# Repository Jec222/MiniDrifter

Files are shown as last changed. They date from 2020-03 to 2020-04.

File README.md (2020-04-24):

# Mini Drifter

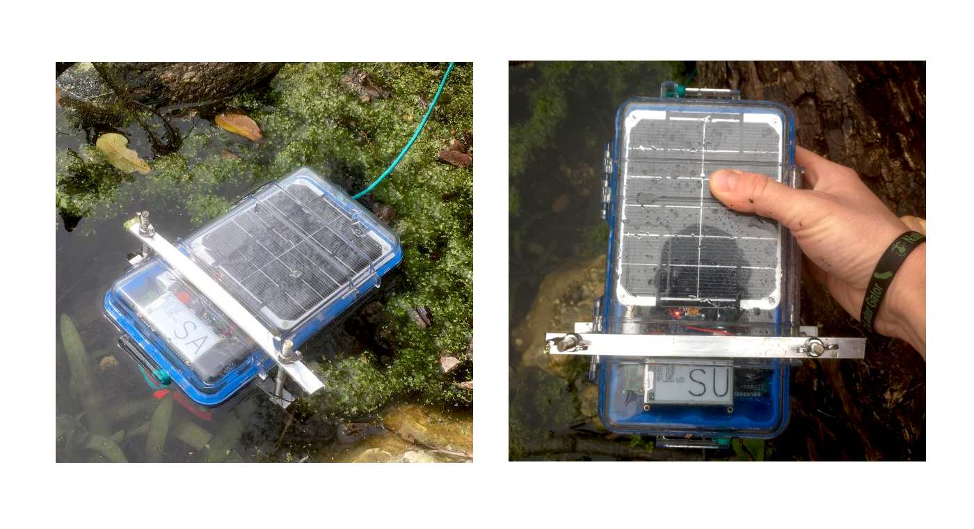
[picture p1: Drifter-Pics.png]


Code and 3d print files for our Senior Design project. The mini drifter is a solar powered smart buoy designed to survive a year with minimal maintenence. It's housing is a modified pelican 1060 case, with a 3d-printed sensor guard epoxied to the bottom.

## Code conventions
### Function prefixes
Code is organized into functions by component, with prefixes denoting the component that the function relates to.
For example:

```
void sd_foo() {
   //Do something with sd card
}
```

this would be the name of a function foo that exists for interacting with the sd card. As a more concrete example, here's our function that sets up the epaper display:
```
void epaper_setup() {
  epd.begin();
  epd.setTextWrap(true);
  epd.setTextSize(2);
}
```

and all other functions related to the epaper display will also begin with "epaper\_"

### Camel case after prefix
After the prefix of the function, camel case is used. For example:
```
void epaper_doTheThing() {
  //Stuff
}
```

## Organization of functions

The first function in the file should be arduino's setup() function, followed by loop(), then the componenent specific functions (which should be grouped together by component).

# 3d print files

The 3d print for the sensor guard is in the SensorGuardPrint folder. It is provided both as a .gcode file and a .stl file to acommadate different types of printers.

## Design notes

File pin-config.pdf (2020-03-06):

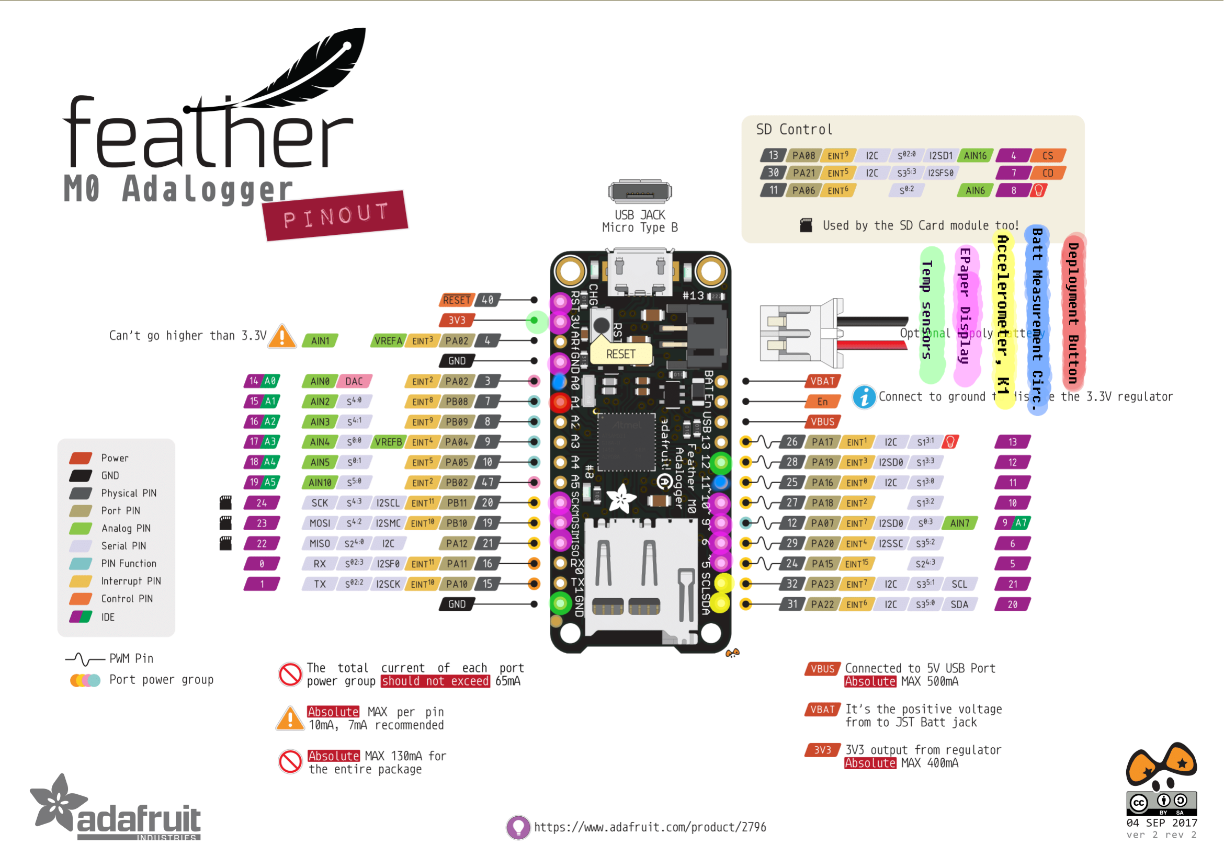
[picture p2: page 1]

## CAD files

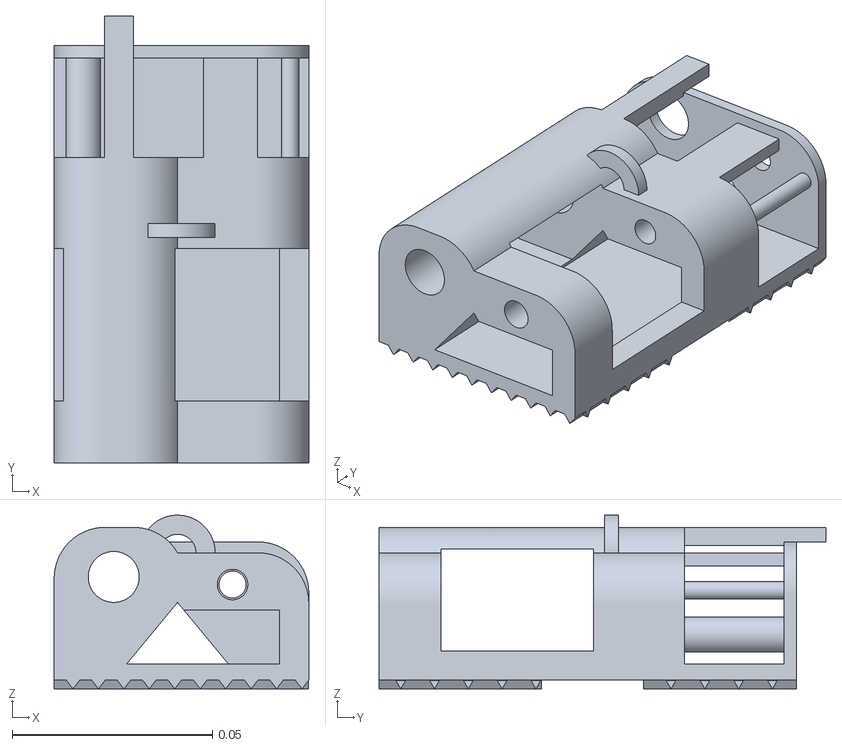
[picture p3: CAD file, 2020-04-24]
SensorGuardPrint/SensorGuard.stl
0.0635 x 0.112 x 0.0433

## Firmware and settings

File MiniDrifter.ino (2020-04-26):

#include <SPI.h>
#include <SD.h>
#include "Adafruit_EPD.h"
#include <OneWire.h>
#include <Adafruit_LIS3DH.h>
#include <Adafruit_Sensor.h>
#include <Wire.h> //For i2c with k1.0
#include <DallasTemperature.h>
#include <RTCZero.h>
#include "icons.h"

#define PIN_LED_RED 13 // Red LED on Pin #13
#define PIN_LED_GREEN 8 // Green LED on Pin #8
#define PIN_LED_STATUS 8
#define PIN_VOLTAGE_BATT 14    // Main Battery Voltage on Pin A0 (14 ide)
#define PIN_VOLTAGE_BATT_CIRC_ENABLE 11 //Enable pin for batt reading circuit
#define SAMPLE_INTERVAL_SECONDS 0 // RTC - Sample interval in seconds
#define SAMPLE_INTERVAL_MINUTES 30

#define PIN_VOLTAGE_BATT_BACKUP A7    // Battery Voltage on Pin A7

enum DaysOfWeek {
  SUNDAY,
  MONDAY,
  TUESDAY,
  WEDNESDAY,
  THURSDAY,
  FRIDAY,
  SATURDAY
};

// Time info for RTC
const byte HOURS = 12;
const byte MINUTES = 45;
const byte SECONDS = 0;

// Date info for RTC
const byte DAY = 13;
const byte MONTH = 3;
const byte YEAR = 20;

typedef struct Timestamp {
  byte hours;
  byte minutes;
  byte seconds;
  byte day;
  byte month;
  byte year;
} Timestamp;

RTCZero rtc;
int nextAlarmTimeMinutes;
int nextAlarmTimeSeconds;
char currentDateAndTime[] = "mm/dd/yy-HH:MM";

#define ONE_WIRE_BUS 12 // Data wire is plugged into port 2 on the Arduino
#define cardSelect 4    //Pin for SD card

//Sets pins for ePaper display
#define EPD_RESET   -1 // can set to -1 and share with microcontroller Reset!
#define EPD_BUSY    -1 // can set to -1 to not use a pin (will wait a fixed delay)
#define SD_CS       5
#define SRAM_CS     6
#define EPD_CS      9
#define EPD_DC      10

//Files on SD card
File logFile;
File errorFile;

const int LOG_DECIMAL_PRECISION = 8;
const int NUM_SAMPLES = 5;
const int TIMESTAMP_SIZE = 8 + strlen("-XX::XX");
const int LOG_DATA_STRING_SIZE = (LOG_DECIMAL_PRECISION * 5) + TIMESTAMP_SIZE + NUM_SAMPLES + 8;
char logLine[LOG_DATA_STRING_SIZE] = "";
char errorLine[750] = ""; // so 1024 is definitely just for now but man, I feel like for our scope, the whole calculation for log_data_string_size is overkill
                          //it does lend well to extension so i guess its alright
const int TEMP_COMP_LENGTH = 8;
char tempComp[TEMP_COMP_LENGTH] = "";


#define ERROR_MESSAGE_DRIFTER_INVERTED "Drifter was inverted, samples weren't taken."
#define ERROR_MESSAGE_NO_SD "No sd card was detected, couldn't log measurements."

struct SystemErrors {
  bool noSdDetected;
  bool drifterInverted;
  bool mainBatteryDepleted;
};

struct SystemErrors systemErrors = {false, false, false};

#define MAX_BATTERY_VOLTAGE 4.2
#define MIN_BATTERY_VOLTAGE 3.0
int mainBatteryLevelPercent;

#define LOW_TEMP_BOUND  30
#define HIGH_TEMP_BOUND 200

const char logFileName[15] = "/DATA.CSV";
const char errorFileName[15] = "/ERRORS.TXT";

#define READ_COMMAND "R"
#define SLEEP_COMMAND "sleep"
#define TEMP_COMPENSATION "T"

//K1.0 stuff
#define K1_ADDRESS 100              //default I2C ID number for EZO EC Circuit.
byte k1ReturnCode;
char k1Data[32];
int k1DelayTime = 570;
char k1InChar;
char *ec;                        //char pointer used in string parsing.
char *tds;                       //char pointer used in string parsing.
char *sal;                       //char pointer used in string parsing.
char *sg;                        //char pointer used in string parsing.
float ec_float;
float tds_float;
float sal_float;
float sg_float;

//For serial input (Serial doesn't work with sleep/wake mode enabled)
bool serialInputComplete;
String serialInput;

//Error Handling Codes
int internal_error_code;
int external_error_code;
int ec_OoB;
int tds_OoB;
int sal_OoB;
bool internal_extra_error;
bool external_extra_error;
bool k1_extra_error;


#define NO_ERROR 0
#define NO_CONNECTION 1
#define FAILED_ONCE   2
#define OUT_OF_BOUNDS 3
#define WITHIN_BOUNDS 4

uint8_t i;
uint8_t samples_taken;

//Accelerometer
Adafruit_LIS3DH accelerometer = Adafruit_LIS3DH();
#define I2C_ADDRESS_ACCELEROMETER 0x18 // change this to 0x19 for alternative i2c address
#define ACCELEROMETER_RANGE LIS3DH_RANGE_4_G  // 2, 4, 8 or 16 G!
typedef struct AccelerometerReading {
  float x;
  float y;
  float z;
};

float intTempF;
float extTempF;

// Setup a oneWire instance to communicate with any OneWire devices (not just Maxim/Dallas temperature ICs)
OneWire oneWire(ONE_WIRE_BUS);

// Pass our oneWire reference to Dallas Temperature.
DallasTemperature sensors(&oneWire);

// arrays to hold device address
DeviceAddress internalThermometer = {0x28, 0x31, 0x74, 0xE3, 0x08, 0x00, 0x00, 0x52};
DeviceAddress externalThermometer = {0x28, 0x9C, 0x32, 0x42, 0x0B, 0x00, 0x00, 0xF3};

//Epaper display
Adafruit_SSD1675 epd(250, 122, EPD_DC, EPD_RESET, EPD_CS, SRAM_CS, EPD_BUSY);

void setup() {
  // put your setup code here, to run once:
  Serial.begin(9600);
  delay(10000);
  Serial.println("\nMini Drifter version 1.0");

  pinMode(PIN_LED_RED, OUTPUT);
  pinMode(PIN_LED_GREEN, OUTPUT);
  pinMode(PIN_LED_STATUS, OUTPUT);
  pinMode(PIN_VOLTAGE_BATT_CIRC_ENABLE, OUTPUT);
  
  digitalWrite(PIN_VOLTAGE_BATT_CIRC_ENABLE, LOW);

  Timestamp initialTime;
  initialTime.hours = HOURS;
  initialTime.minutes = MINUTES;
  initialTime.seconds = SECONDS;
  initialTime.day = DAY;
  initialTime.month = MONTH;
  initialTime.year = YEAR;

  rtc_setup(initialTime);
  sd_setup();
  temp_setup();
  accelerometer_setup();
  k1_setup();
  epaper_setup();

  internal_error_code = 0;
  external_error_code = 0;
  internal_extra_error = false;
  external_extra_error = false;
  k1_extra_error = false;
  ec_OoB = 0;
  tds_OoB = 0;
  sal_OoB = 0;

  i = 0;
  samples_taken = 1;
  k1_sleep();
}

void loop() {
  // put your main code here, to run repeatedly:
  blink(PIN_LED_GREEN, 2);
  blink(PIN_LED_STATUS, 4);
  sd_setup();
  sd_openFiles();
  
  getDate();

  float battN = (drifter_readMainBatteryVoltage() - MIN_BATTERY_VOLTAGE) / (MAX_BATTERY_VOLTAGE - MIN_BATTERY_VOLTAGE);
  if (battN < 0) {
    battN = 0;
  }
  Serial.println(battN);
  mainBatteryLevelPercent = (battN) * 100.0;
  bool needToUpdateEpaper = false;

  if (systemErrors.mainBatteryDepleted) {
    if (mainBatteryLevelPercent > 0) {
      errorFile.write(currentDateAndTime);
      errorFile.write(" succesfully regained power.\n");
      errorFile.flush();
      systemErrors.mainBatteryDepleted = false;
      needToUpdateEpaper = true;
    }
  } else {
    if (mainBatteryLevelPercent == 0) {
      systemErrors.mainBatteryDepleted = true;
      errorFile.write(currentDateAndTime);
      errorFile.write(" Entered power recovery mode.\n");
      errorFile.flush();
      epaper_clear();
      epaper_drawPowerRecoveryModeIcon();
    }
      needToUpdateEpaper = true;
  }

  AccelerometerReading accel = accelerometer_read();
  systemErrors.drifterInverted = accel.z < 0;

  if (!systemErrors.mainBatteryDepleted) {
    if (systemErrors.drifterInverted) {
      /* Drifter is not upright, don't take samples */
    } else {
      if (!systemErrors.noSdDetected) {
        temp_handle_measurement();
        k1_handle_measurement();  
        epaper_clear();
        epaper_drawSensorData();
        if (internal_error_code != 0 || external_error_code != 0 || k1ReturnCode != 1 || ec_OoB != 0 || tds_OoB != 0 || sal_OoB != 0) {
          epaper_drawSensorIcons();
        } else {
          epaper_drawDayCode();
        }
        sd_logError();
        sd_logData();
        needToUpdateEpaper = true;
      }
    }

    drifter_handleSystemErrors();
  }
  Serial.println(needToUpdateEpaper);
  if (needToUpdateEpaper) epaper_update();
  i++;
  samples_taken++;
  sd_closeFiles();
  rtc_enterDeepSleep();
}

void rtc_setup(Timestamp initialTime) {
  rtc.begin();
  rtc.setTime(initialTime.hours, initialTime.minutes, initialTime.seconds);
  rtc.setDate(initialTime.day, initialTime.month, initialTime.year);
  nextAlarmTimeMinutes = initialTime.minutes;
  nextAlarmTimeSeconds = initialTime.seconds;
}

void rtc_enterDeepSleep() {
  nextAlarmTimeSeconds = nextAlarmTimeSeconds + SAMPLE_INTERVAL_SECONDS;
  if (nextAlarmTimeSeconds >= 60) {
    nextAlarmTimeMinutes += 1;
    nextAlarmTimeSeconds = nextAlarmTimeSeconds % 60;
  }
  nextAlarmTimeMinutes = (nextAlarmTimeMinutes + SAMPLE_INTERVAL_MINUTES) % 60;


  rtc.setAlarmSeconds(nextAlarmTimeSeconds);
  rtc.setAlarmMinutes(nextAlarmTimeMinutes);
  rtc.enableAlarm(rtc.MATCH_MMSS); // Match minutes and seconds
  rtc.attachInterrupt(alarmMatch); // Attaches function to be called, currently blank
  delay(50); // Brief delay prior to sleeping not really sure its required

  blink(PIN_LED_GREEN, 2);
  rtc.standbyMode();    // Sleep until next alarm match
  // Code re-starts here after sleep!
}

void alarmMatch() {}

// blink led
void blink(uint8_t LED, uint8_t flashes) {
  uint8_t i;
  for (i=0; i<flashes; i++) {
    digitalWrite(LED, HIGH);
    delay(100);
    digitalWrite(LED, LOW);
    delay(200);
  }
}

void sd_setup() {
  bool logFileEmpty = false;

  if (!SD.begin(cardSelect)) {
    Serial.println("Couldn't initialize SD card");
    systemErrors.noSdDetected = true;
  } else {
    systemErrors.noSdDetected = false;
    logFileEmpty = !SD.exists(logFileName);
  }

  sd_openFiles();

  if(!systemErrors.noSdDetected) {

    if (logFileEmpty) {
      //File didn't previously exist, print header at top
      sprintf(logLine, "mm/dd/yy-HH:MM,Int,Ext,Tds,Sal,Con,Bat%\n");
      logFile.write(logLine);
    }

  logFile.flush();
  }

  sd_closeFiles();
}

void sd_openFiles() {

  if (!systemErrors.noSdDetected) {

    logFile = SD.open(logFileName, FILE_WRITE);
    errorFile = SD.open(errorFileName, FILE_WRITE);

    if (!logFile) {
      Serial.println("Couldn't open log file");
      systemErrors.noSdDetected = true;
    }

    if (!errorFile) {
      Serial.println("Couldn't open error file");
      systemErrors.noSdDetected = true;
    }
  }
}

void sd_closeFiles() {
  if (logFile)
    logFile.close();

  if (errorFile)
    errorFile.close();
}

void sd_logData() {
  sprintf(logLine, "%s,%.2f,%.2f,%.2f,%.2f,%.2f,%.2f\n", currentDateAndTime, intTempF, extTempF, tds_float, sal_float, ec_float, drifter_readMainBatteryVoltage());
  logFile.write(logLine);
  for (int i = 0; i < LOG_DATA_STRING_SIZE; i++) {
    logLine[i] = '\0';
  }
  logFile.flush();
}

void sd_logError() {
  //if there are errors log them otherwise do nothing
  if(internal_error_code != 0 || external_error_code != 0 || k1ReturnCode != 1 || ec_OoB != 0 || tds_OoB != 0 || sal_OoB != 0){

    strcpy(errorLine,currentDateAndTime);
    strcat(errorLine, "\n");

    if(internal_extra_error)
      strcat(errorLine, "\tInternal Temperature sensor connection not established. Trying again ... connection established.\n");

    switch (internal_error_code) {
      case 1:
        strcat(errorLine, "\tInternal Temperature sensor connection not established. Trying again ... could not be established.\n");
        break;

      case 3:
        strcat(errorLine, "\tInternal Temperature out of bounds. Trying again ... sample out of bounds.\n");
        break;

      case 4:
        strcat(errorLine, "\tInternal Temperature out of bounds. Trying again ... sample within bounds.\n");
        break;
      default:
        break;
    }

    if(external_extra_error)
      strcat(errorLine, "\tExternal Temperature sensor connection not established. Trying again ... connection established.\n");

    switch (external_error_code) {
      case 1:
        strcat(errorLine, "\tExternal Temperature sensor connection not established. Trying again ... could not be established.\n");
        break;

      case 3:
        strcat(errorLine, "\tExternal Temperature out of bounds. Trying again ... sample out of bounds.\n");
        break;

      case 4:
        strcat(errorLine, "\tExternal Temperature out of bounds. Trying again ... sample within bounds.\n");
        break;
      default:
        break;
    }

    switch(k1ReturnCode){
      case 0:
        strcat(errorLine, "\tK1 Probe - Data returned Null\n");
        break;

      case 2:
        strcat(errorLine, "\tK1 Probe - Command has failed. Trying again ... command failure.\n");
        break;

      case 254:
        strcat(errorLine, "\tK1 Probe - Command pending error.\n");
        break;

      case 255:
        strcat(errorLine, "\tK1 Probe - Connection not established ... could not be established.\n");
        break;
      default:
        break;
    }

    if(k1_extra_error)
      strcat(errorLine, "\tK1 Probe - Connection not established ... connection established.\n");

    switch(tds_OoB){
      case 1:
        strcat(errorLine, "\tTDS sensor out of bounds. Trying again ... sample within bounds\n");
        break;
      case 2:
        strcat(errorLine, "\tTDS sensor out of bounds. Trying again ... sample out of bounds\n");
        break;
      default:
        break;
    }
    switch(ec_OoB){
      case 1:
        strcat(errorLine, "\tConductivity sensor out of bounds. Trying again ... sample within bounds\n");
        break;
      case 2:
        strcat(errorLine, "\tConductivity sensor out of bounds. Trying again ... sample out of bounds\n");
        break;
      default:
        break;
    }
    switch(sal_OoB){
      case 1:
        strcat(errorLine, "\tSalinity sensor out of bounds. Trying again ... sample within bounds\n");
        break;
      case 2:
        strcat(errorLine, "\tSalinity sensor out of bounds. Trying again ... sample out of bounds\n");
        break;
      default:
        break;
    }


    internal_error_code = 0;
    external_error_code = 0;
    ec_OoB = 0;
    tds_OoB = 0;
    sal_OoB = 0;
    internal_extra_error = false;
    external_extra_error = false;
    k1_extra_error = false;

    errorFile.write(errorLine);
    for (int i = 0; i < 128; i++) {
      errorLine[i] = '\0';
    }
  }
}

void getDate(){
  sprintf(currentDateAndTime, "%d/%d/%d-%d:%02d", rtc.getMonth(), rtc.getDay(), rtc.getYear(), rtc.getHours(), rtc.getMinutes());
}

void drifter_handleSystemErrors() {

  if (systemErrors.noSdDetected) {
    sd_closeFiles();
    epd.clearBuffer();
    epaper_drawSdCardErrorIcon();
    sd_setup();
  }

  if (systemErrors.drifterInverted) {
    errorFile.write(currentDateAndTime);
    errorFile.write(" ");
    errorFile.write(ERROR_MESSAGE_DRIFTER_INVERTED);
    errorFile.write("\n");
    errorFile.flush();
  }
}

void epaper_setup() {
  epd.begin();
  epd.setTextWrap(true);
  epd.setTextSize(1);
  epd.setTextColor(EPD_BLACK);
}

void epaper_draw1BitIcon(const unsigned char *bytes, const int width, const int height, const int xPos, const int yPos) {
  for (int y = 0; y < height; y++) {
    for (int x = 0; x < width; x++) {
      if (icon_pixelIsOn(bytes, width, height, x, y)) {
        epd.drawPixel(xPos + x, yPos + y, EPD_BLACK);
      }
    }
  }
}

void epaper_drawPowerRecoveryModeIcon() {
  epd.setTextSize(1);
  epd.setCursor(0, 25);
  epd.print("Entered power\nrecovery mode\n");
  epd.print(currentDateAndTime);
  epaper_draw1BitIcon(BATTERY_ICON_BYTES, BATTERY_ICON_WIDTH, BATTERY_ICON_HEIGHT, 121, 13);
}

void epaper_drawSdCardErrorIcon() {
  epd.setTextSize(1);
  epd.setCursor(0, 25);
  epd.print("No SD card...\n\nPlease insert\nSD.");
  epaper_draw1BitIcon(NO_SD_ICON_BYTES, NO_SD_ICON_WIDTH, NO_SD_ICON_HEIGHT, 121, 13);
}

void epaper_clear() {
  epd.clearBuffer();
}

void epaper_update() {
  epd.display();
}

void epaper_drawSensorData() {
    epd.setCursor(2, 2);
    epd.setTextSize(1);
    if (systemErrors.drifterInverted) {
      epd.print("Not upright");
      epd.print("\nInt: ");
      epd.print(intTempF);
      epd.print("\nExt: NA");
      epd.print("\nTDS: NA");
      epd.print("\nCon: NA");
      epd.print("\nSal: NA");
      epd.print("\nBat: ");
      epd.print(mainBatteryLevelPercent);
      epd.print("%, ");
      epd.print(drifter_readMainBatteryVoltage());
      epd.print("V\n");
      epd.print("%\n");
    } else {
      epd.print("MiniDrifter");
      epd.print("\nInt: ");
      epd.print(intTempF);
      epd.print("\nExt: ");
      epd.print(extTempF);
      epd.print("\nTDS: ");
      epd.print(tds_float);
      epd.print("\nCon: ");
      epd.print(ec_float);
      epd.print("\nSal: ");
      epd.print(sal_float);
      epd.print("\nBat: ");
      epd.print(mainBatteryLevelPercent);
      epd.print("%, ");
      epd.print(drifter_readMainBatteryVoltage());
      epd.print("V\n");
      epd.print(samples_taken);
      epd.print(" samples taken");
    }
}

void epaper_drawSensorIcons() {
    epaper_draw1BitIcon(SENSOR_ICON_BYTES, SENSOR_ICON_WIDTH, SENSOR_ICON_HEIGHT, 121, 0);
    
    int x_dimension = 70;
    int y_dimension = 95;
    int offset = 10;

    epd.setCursor(x_dimension, y_dimension);
  
    switch(internal_error_code){
      case NO_ERROR:
        break;
      case NO_CONNECTION:
        epd.print("Int temp sensor disconnected");
        y_dimension += offset;
        break;
      case OUT_OF_BOUNDS:
        epd.print("Int temp out of bounds");
        y_dimension += offset; 
        break;
      default:
        break;
    }

    epd.setCursor(x_dimension, y_dimension);
    
    switch(external_error_code){
      case NO_ERROR:
        break;
      case NO_CONNECTION:
        epd.print("Ext temp sensor disconnected");
        y_dimension += offset;
        break;
      case OUT_OF_BOUNDS:
        epd.print("Ext temp out of bounds");
        y_dimension += offset;   
        break;
      default:
        break;
    }

    epd.setCursor(x_dimension, y_dimension);
        
    switch(k1ReturnCode){
      case 0:
        epd.print("K1 - Null values");
        break;
      case 2:
        epd.print("K1 - Command Failed");
        break;
      case 254:
        epd.print("K1 - Pending");
        break;
      case 255:
        epd.print("K1 Chip disconnected");
        break;
      case 1:
      case 3:
      case 256:
        if(ec_OoB == 1 || tds_OoB == 1 || sal_OoB == 1){
          epd.print("K1 - out of bounds");
          //write "K1 Probe disconnected"
        }
        break;
      default:
        break;
    }
}

void epaper_drawDayCode() {
  const int dayOfWeek = drifter_getDayOfWeek(rtc.getYear(), rtc.getMonth(), rtc.getDay());

  Serial.print("day of week = ");
  Serial.println(dayOfWeek);
  
  switch(dayOfWeek) {
    case SUNDAY:
      epaper_draw1BitIcon(SUNDAY_ICON_BYTES, SUNDAY_ICON_WIDTH, SUNDAY_ICON_HEIGHT, 105, 9);
    break;
    case MONDAY:
      epaper_draw1BitIcon(MONDAY_ICON_BYTES, MONDAY_ICON_WIDTH, MONDAY_ICON_HEIGHT, 105, 9);
    break;
    case TUESDAY:
      epaper_draw1BitIcon(TUESDAY_ICON_BYTES, TUESDAY_ICON_WIDTH, TUESDAY_ICON_HEIGHT, 105, 9);
    break;
    case WEDNESDAY:
      epaper_draw1BitIcon(WEDNESDAY_ICON_BYTES, WEDNESDAY_ICON_WIDTH, WEDNESDAY_ICON_HEIGHT, 105, 9);
    break;
    case THURSDAY:
      epaper_draw1BitIcon(THURSDAY_ICON_BYTES, THURSDAY_ICON_WIDTH, THURSDAY_ICON_HEIGHT, 105, 9);
    break;
    case FRIDAY:
      epaper_draw1BitIcon(FRIDAY_ICON_BYTES, FRIDAY_ICON_WIDTH, FRIDAY_ICON_HEIGHT, 105, 9);
    break;
    case SATURDAY:
      epaper_draw1BitIcon(SATURDAY_ICON_BYTES, SATURDAY_ICON_WIDTH, SATURDAY_ICON_HEIGHT, 105, 9);
    break;
    default:
    break;
  }
}

void temp_setup() {
  // locate devices on the bus
  sensors.begin();

  //parasite power is off

  // set the resolution to 9 bit (Each Dallas/Maxim device is capable of several different resolutions)
  sensors.setResolution(internalThermometer, 9);
}

void temp_readTemperatures() {
  sensors.requestTemperatures();
  float tempC = sensors.getTempC(internalThermometer);
  intTempF = DallasTemperature::toFahrenheit(tempC);

  tempC = sensors.getTempC(externalThermometer);
  extTempF = DallasTemperature::toFahrenheit(tempC);
}

/*
 *Takes a reading from the temperature sensors
 *Checks for a valid connection by comparing the received data against a default value.
 *
 *thinking about using an error code like the K1 uses.
 *int internal_error_code;
 *int external_error_code;
 *0 = no error. should be by default
 *1 = connection failed twice
 *2 = failed but connection established
 *3 = out of bounds twice
 *4 = out of bounds but inside second try
 *internal_extra error = failed to connect once but worked second time BUT out of bounds. instead of writing 2 extra cases each time I'll write 3 bool values for each sensor.
 *error code reset in the single error write
 */
void temp_handle_measurement(){
  temp_readTemperatures();



  //connection check
  if(intTempF < -196){
    temp_readTemperatures();

    if(intTempF < -196){
      internal_error_code = 1;
      intTempF = -1;
    }
    else
      internal_error_code = 2;
  }
  //Bounds check
  if(internal_error_code == 0 || internal_error_code == 2){
    if(internal_error_code == 2)
      internal_extra_error = true;
    if(intTempF < LOW_TEMP_BOUND || intTempF > HIGH_TEMP_BOUND){
      temp_readTemperatures();
      if(intTempF < LOW_TEMP_BOUND || intTempF > HIGH_TEMP_BOUND){
        intTempF = -1;
        internal_error_code = 3;
      }
      else
        internal_error_code = 4;
    }
  }

  //connection check
  if(extTempF < -196){
    temp_readTemperatures();
    if(extTempF < -196){
      external_error_code = 1;
      extTempF = -1;
    }
    else
      external_error_code = 2;
  }

  //Bounds check
  if(external_error_code == 0 || external_error_code == 2){
    if(external_error_code == 2)
      external_extra_error = true;
    if(extTempF < LOW_TEMP_BOUND || extTempF > HIGH_TEMP_BOUND){
      temp_readTemperatures();
      if(extTempF < LOW_TEMP_BOUND || extTempF > HIGH_TEMP_BOUND){
        extTempF = -1;
        external_error_code = 3;
      }
      else
        external_error_code = 4;
    }
  }
}

void accelerometer_setup() {
  if (!accelerometer.begin(I2C_ADDRESS_ACCELEROMETER)) {
    Serial.println("Couldnt start accelerometer");
  } else {
    accelerometer.setRange(ACCELEROMETER_RANGE);
  }
}
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

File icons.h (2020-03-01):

#ifndef MINI_DRIFTER_ICONS_H
#define MINI_DRIFTER_ICONS_H

// Pass in the bytes of the 1 bit-per-pixel icon along with it's width, height, and the desired x/y
// coordinates to see if the specified pixel is on or off. These icons are essentially bit masks that tell 
// you where to draw pixels and where to leave the screen blank. An external program was written in C to
// convert black and white images to these 1bpp bit masks and output them as a C array, which was then
// copy/pasted into this file.

bool icon_pixelIsOn(const unsigned char *iconBytes, const int iconWidth, const int iconHeight, int x, int y) {
  if (x >= iconWidth || y >= iconHeight || x < 0 || y < 0) {
    return false;
  }
  
  const int widthBytes = iconWidth >> 3;
  const int bitShift = 7 - (x % 8);
  
  return iconBytes[(y*widthBytes) + (x >> 3)] & (1 << bitShift);
}

const int NO_SD_ICON_WIDTH = 128;
const int NO_SD_ICON_HEIGHT = 96;

const unsigned char NO_SD_ICON_BYTES[1536] = {
  0x00, 0x01, 0xff, 0xff, 0xf8, 0x00, 0xff, 0xff, 0xff, 0xff, 0xff, 0xff, 0xff, 0xff, 0xff, 0xfe, 
  0x00, 0x03, 0xff, 0xff, 0xf8, 0x01, 0xff, 0xff, 0xff, 0xff, 0xff, 0xff, 0xff, 0xff, 0xff, 0xfe, 
  0x00, 0x07, 0xff, 0xff, 0xfc, 0x01, 0xff, 0xff, 0xff, 0xff, 0xff, 0xff, 0xff, 0xff, 0xff, 0xfe, 
  0x00, 0x0f, 0xff, 0xff, 0xfc, 0x03, 0xff, 0xff, 0xff, 0xff, 0xff, 0xff, 0xff, 0xff, 0xff, 0xfe, 
  0x00, 0x1f, 0x00, 0x00, 0x0f, 0xff, 0x80, 0x00, 0x00, 0x00, 0x00, 0x00, 0x00, 0x00, 0x00, 0x1e, 
  0x00, 0x3e, 0x00, 0x00, 0x07, 0xff, 0x00, 0x00, 0x00, 0x00, 0x00, 0x00, 0x00, 0x00, 0x00, 0x1e, 
  0x00, 0x7c, 0x00, 0x00, 0x07, 0xff, 0x00, 0x00, 0x00, 0x00, 0x00, 0x00, 0x00, 0x00, 0x00, 0x1e, 
  0x00, 0xf8, 0x00, 0x00, 0x03, 0xfe, 0x00, 0x00, 0x00, 0x00, 0x00, 0x00, 0x00, 0x00, 0x00, 0x1e, 
  0x01, 0xf0, 0x00, 0x00, 0x00, 0x00, 0x00, 0x00, 0x00, 0x00, 0x00, 0x00, 0x00, 0x00, 0x00, 0x1e, 
  0x03, 0xe0, 0x00, 0x00, 0x00, 0x00, 0x00, 0x00, 0x00, 0x00, 0x00, 0x00, 0x00, 0x00, 0x00, 0x1e, 
  0x07, 0xc0, 0x01, 0x80, 0x00, 0x00, 0x00, 0x00, 0x00, 0x00, 0x00, 0x00, 0x00, 0x00, 0x00, 0x1e, 
  0x0f, 0x80, 0x1f, 0x80, 0x00, 0x00, 0x00, 0x00, 0x00, 0x00, 0x00, 0x00, 0x00, 0x00, 0x00, 0x1e, 
  0x1f, 0x00, 0x7f, 0x80, 0x00, 0x00, 0x00, 0x00, 0x00, 0x00, 0x00, 0x00, 0x00, 0x00, 0x00, 0x1e, 
  0x3e, 0x00, 0x7f, 0x80, 0x00, 0x00, 0x00, 0x00, 0x00, 0x00, 0x00, 0x00, 0x00, 0x00, 0x00, 0x1e, 
  0x7c, 0x00, 0x1f, 0x80, 0x00, 0x00, 0x00, 0x00, 0x00, 0x00, 0x00, 0x00, 0x00, 0x00, 0x00, 0x1e, 
  0xf8, 0x00, 0x01, 0x80, 0x00, 0x00, 0x00, 0x00, 0x00, 0x00, 0x00, 0x00, 0x00, 0x00, 0x00, 0x1e, 
  0xf8, 0x00, 0x00, 0x00, 0x00, 0x00, 0x00, 0x00, 0x00, 0x00, 0x00, 0x00, 0x00, 0x00, 0x00, 0x1e, 
  0xf8, 0x00, 0x00, 0x00, 0x00, 0x00, 0x00, 0x00, 0x00, 0x00, 0x00, 0x00, 0x00, 0x00, 0x00, 0x1e, 
  0xf8, 0x00, 0x00, 0x00, 0x00, 0x00, 0x00, 0x00, 0x08, 0x00, 0x00, 0x00, 0x00, 0x00, 0x00, 0x1e, 
  0xf8, 0x00, 0x00, 0x00, 0x00, 0x00, 0x0f, 0xf0, 0x3e, 0x00, 0x00, 0x00, 0x00, 0x00, 0x00, 0x1e, 
  0xf8, 0x00, 0x00, 0x00, 0x00, 0x00, 0x1f, 0xf8, 0x3f, 0x00, 0x00, 0x00, 0x00, 0x00, 0x00, 0x1e, 
  0xf8, 0x00, 0x00, 0x00, 0x00, 0x00, 0x1f, 0xfc, 0x7f, 0x00, 0x00, 0x00, 0x00, 0x00, 0x00, 0x1e, 
  0xf8, 0x00, 0x00, 0x00, 0x00, 0x00, 0x3e, 0x7c, 0x7f, 0x80, 0x00, 0x00, 0x00, 0x00, 0x00, 0x1e, 
  0xf8, 0x00, 0x00, 0x00, 0x00, 0x00, 0x3c, 0x3c, 0xff, 0xc0, 0x00, 0x00, 0x00, 0x00, 0x00, 0x1e, 
  0xf8, 0x00, 0x00, 0x00, 0x00, 0x00, 0x3c, 0x3c, 0xff, 0xc0, 0x00, 0x00, 0x00, 0x00, 0x00, 0x1e, 
  0xf8, 0x00, 0x00, 0x00, 0x00, 0x00, 0x3e, 0x7c, 0xff, 0xc0, 0x00, 0x00, 0x00, 0x00, 0x00, 0x1e, 
  0xf8, 0x00, 0x00, 0x00, 0x00, 0x00, 0x1f, 0xfc, 0xff, 0xc0, 0x00, 0x00, 0x00, 0x00, 0x00, 0x1e, 
  0xf8, 0x00, 0x00, 0x00, 0x00, 0x00, 0x1f, 0xf9, 0xff, 0xc0, 0x00, 0x00, 0x00, 0x00, 0x00, 0x1e, 
  0xf8, 0x00, 0x00, 0x00, 0x00, 0x00, 0x0f, 0xf1, 0xff, 0xe0, 0x00, 0x00, 0x00, 0x00, 0x00, 0x1e, 
  0xf8, 0x00, 0x00, 0x00, 0x00, 0x00, 0x00, 0x01, 0xc7, 0xe0, 0x00, 0x00, 0x00, 0x00, 0x00, 0x1e, 
  0xf8, 0x00, 0x00, 0x00, 0x00, 0x00, 0x0e, 0x01, 0xc7, 0xe0, 0x00, 0x00, 0x00, 0x00, 0x00, 0x1e, 
  0xf8, 0x00, 0x00, 0x00, 0x00, 0x00, 0x1e, 0x01, 0xc3, 0xe0, 0x00, 0x00, 0x00, 0x00, 0x00, 0x1e, 
  0xf8, 0x00, 0x00, 0x00, 0x00, 0x00, 0x3e, 0x01, 0xc3, 0xe0, 0x00, 0x00, 0x00, 0x00, 0x00, 0x1e, 
  0xf8, 0x00, 0x00, 0x00, 0x00, 0x00, 0x3e, 0x01, 0xc3, 0xe0, 0x00, 0x00, 0x00, 0x00, 0x00, 0x1e, 
  0xf8, 0x00, 0x00, 0x00, 0x00, 0x00, 0x3c, 0x00, 0x03, 0xe0, 0x00, 0x00, 0x00, 0x00, 0x00, 0x1e, 
  0xf8, 0x00, 0x00, 0x00, 0x00, 0x00, 0x3c, 0x01, 0xc3, 0xe0, 0x00, 0x00, 0x00, 0x00, 0x00, 0x1e, 
  0xf8, 0x00, 0x00, 0x00, 0x00, 0x00, 0x3f, 0xfd, 0xc3, 0xe0, 0x00, 0x00, 0x00, 0x00, 0x00, 0x1e, 
  0xf8, 0x00, 0x00, 0x00, 0x00, 0x00, 0x3f, 0xfd, 0xc0, 0x00, 0x00, 0x00, 0x00, 0x00, 0x00, 0x1e, 
  0xf8, 0x00, 0x00, 0x00, 0x00, 0x00, 0x1f, 0xfd, 0xc7, 0x80, 0x00, 0x00, 0x00, 0x00, 0x00, 0x1e, 
  0xf8, 0x00, 0x00, 0x00, 0x00, 0x00, 0x0f, 0xfd, 0xcf, 0xc0, 0x00, 0x00, 0x00, 0x00, 0x00, 0x1e, 
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
};

const int BATTERY_ICON_WIDTH = 128;
const int BATTERY_ICON_HEIGHT = 96;
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

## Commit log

2020-01-22 adding pin-config pdf
2020-02-04 Adding initial k1 code The k1 works by putting commands in serial currently. It still needs to be integrated to be in the actual sensor loop.
2020-02-05 Adding accelerometer support Initial inversion detection pass
2020-02-07 Initial system error handling
    [MiniDrifter.ino]
2020-02-07 Adding sleep/wake of feather and k1 Still need to add sleep for accelerometer, and switch to parasitic power for temp sensors. Also write error handling.
    [MiniDrifter.ino]
2020-02-10 Added k1 error handling
    Will work on temperatures next
    [MiniDrifter.ino]
2020-02-17 Adding timestamp string & sd card error handling
    Added a global string that's just the current timestamp. SD card removal
    now results in an error indication on the display. Putting the sd card
    back in the drifter causes it to resume normal operation.
    [MiniDrifter.ino]
2020-02-19 Added Temp Error Handling
    [MiniDrifter.ino]
2020-02-21 enabled deep sleep for 30 minutes. Preparing for full testing in my bakcyard. I uncommented the line that puts it to sleep, made the sample interval 30 minutes, and removed the delay from the end of 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
2020-02-27 Adding 1-bit icon drawing functions
    New functions to draw images represented as 1bpp character arrays.
    This commit also adds the power recovery mode and sd error icons.
    [MiniDrifter.ino, icons.h]
2020-03-01 Adding sensor icon
2020-03-01 temperature Compensation
2020-03-01 Revising sensor icon
2020-03-01 Sensor Icon Errors
    Merged fully with tyler's code should be the most up to date along with the newly added sensor icon error
    [MiniDrifter.ino]
2020-03-02 Fixing seconds support for sample interval
    [MiniDrifter.ino]
2020-03-06 Updating pins for new perf board & pin config pdf
    The new perf board uses pin 11 rather than 13 for the battery voltage circuit
    enable pin. small change to those definitions to correct them. Also added
    all the new pins to the pin-config pdf, its not fully up-to-date.
    [MiniDrifter.ino]
2020-03-06 Fixing power recovery mode issue Now setting the transistor enable pin low in setup()
    [MiniDrifter.ino]
2020-04-24 Adding sensor guard 3d print, revising readme.
    [SensorGuard.stl]
